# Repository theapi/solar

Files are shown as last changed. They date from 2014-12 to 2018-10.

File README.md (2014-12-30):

Solar
=====

Experiments with solar panels

To set up usb serial communication between the Pi and the Arduino:

Install arduino:
```sudo apt-get install arduino```

Give the pi user permission to use the serial connection:
```sudo usermod -a -G dialout pi```

Optionally install nfs for sharing the data log
From http://www.linuxuser.co.uk/tutorials/building-a-network-of-raspberry-pis

```sudo apt-get install nfs-kernel-server```

Make a shared directory
```sudo mkdir /srv/public```

Edit /etc/exports
```/srv/public *(rw,async,no_subtree_check)```

Ensure rpcbind starts on restart
```sudo update-rc.d rpcbind enable```

Connect to the share with
```
sudo mkdir /mnt/solar
sudo mount <SERVER_IP>:/srv/public /mnt/solar
```

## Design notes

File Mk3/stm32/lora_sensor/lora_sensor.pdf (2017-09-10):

## lora_sensor Project Configuration Report

# 1. Description

## 1.1. Project

Project Name | lora_sensor
Board Name | lora_sensor
Generated with: | STM32CubeMX 4.22.0
Date | 09/10/2017

## 1.2. MCU

MCU Series | STM32L0
MCU Line | STM32L0x3
MCU name | STM32L053C8Tx
MCU Package | LQFP48
MCU Pin number | 48

# 2. Pinout Configuration

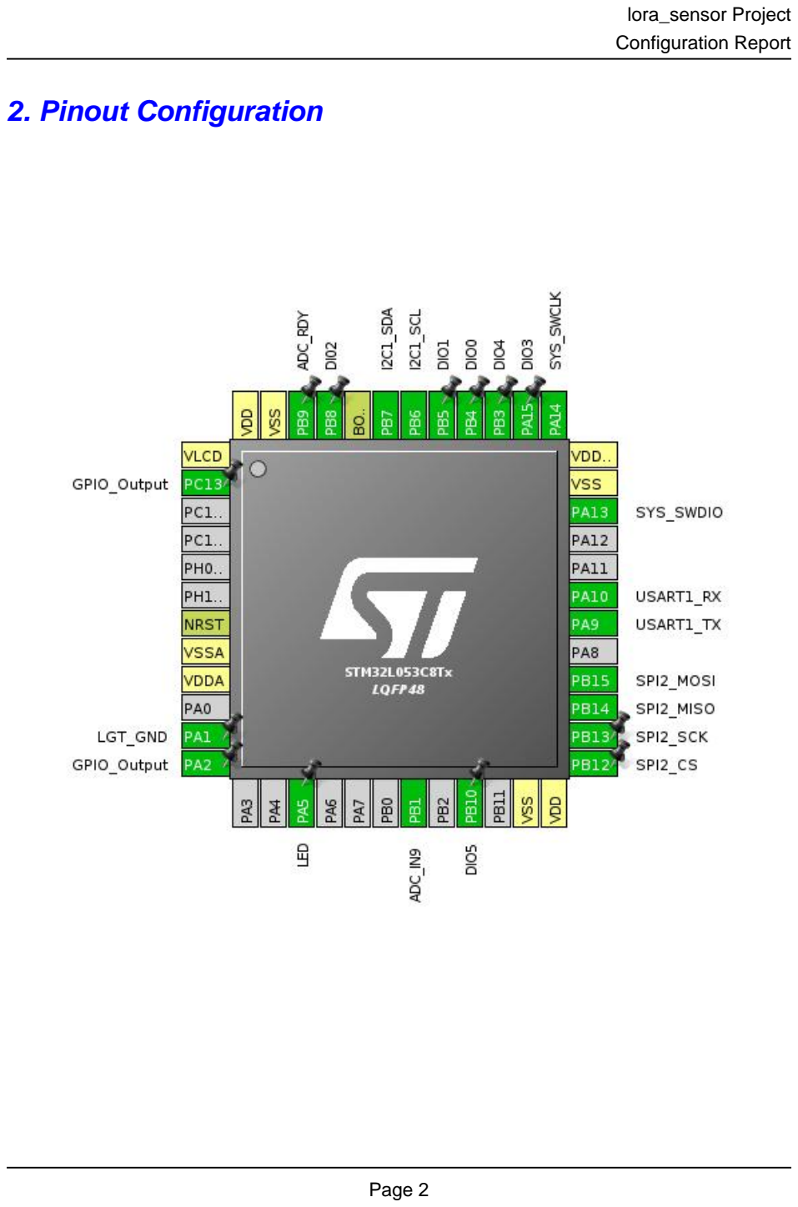
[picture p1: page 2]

# 3. Pins Configuration

Pin Number LQFP48 | Pin Name (function after reset) | Pin Type | Alternate Function(s) | Label
1 | VLCD | Power
2 | PC13 * | I/O | GPIO_Output
7 | NRST | Reset
8 | VSSA | Power
9 | VDDA | Power
11 | PA1 * | I/O | GPIO_Output | LGT_GND
12 | PA2 * | I/O | GPIO_Output
15 | PA5 * | I/O | GPIO_Output | LED
19 | PB1 | I/O | ADC_IN9
21 | PB10 * | I/O | GPIO_Analog | DIO5
23 | VSS | Power
24 | VDD | Power
25 | PB12 * | I/O | GPIO_Output | SPI2_CS
26 | PB13 | I/O | SPI2_SCK
27 | PB14 | I/O | SPI2_MISO
28 | PB15 | I/O | SPI2_MOSI
30 | PA9 | I/O | USART1_TX
31 | PA10 | I/O | USART1_RX
34 | PA13 | I/O | SYS_SWDIO
35 | VSS | Power
36 | VDD_USB | Power
37 | PA14 | I/O | SYS_SWCLK
38 | PA15 * | I/O | GPIO_Analog | DIO3
39 | PB3 * | I/O | GPIO_Analog | DIO4
40 | PB4 | I/O | GPIO_EXTI4 | DIO0
41 | PB5 * | I/O | GPIO_Analog | DIO1
42 | PB6 | I/O | I2C1_SCL
43 | PB7 | I/O | I2C1_SDA
44 | BOOT0 | Boot
45 | PB8 * | I/O | GPIO_Analog | DI02
46 | PB9 | I/O | GPIO_EXTI9 | ADC_RDY
47 | VSS | Power
48 | VDD | Power

## * The pin is affected with an I/O function

# 4. Clock Tree Configuration

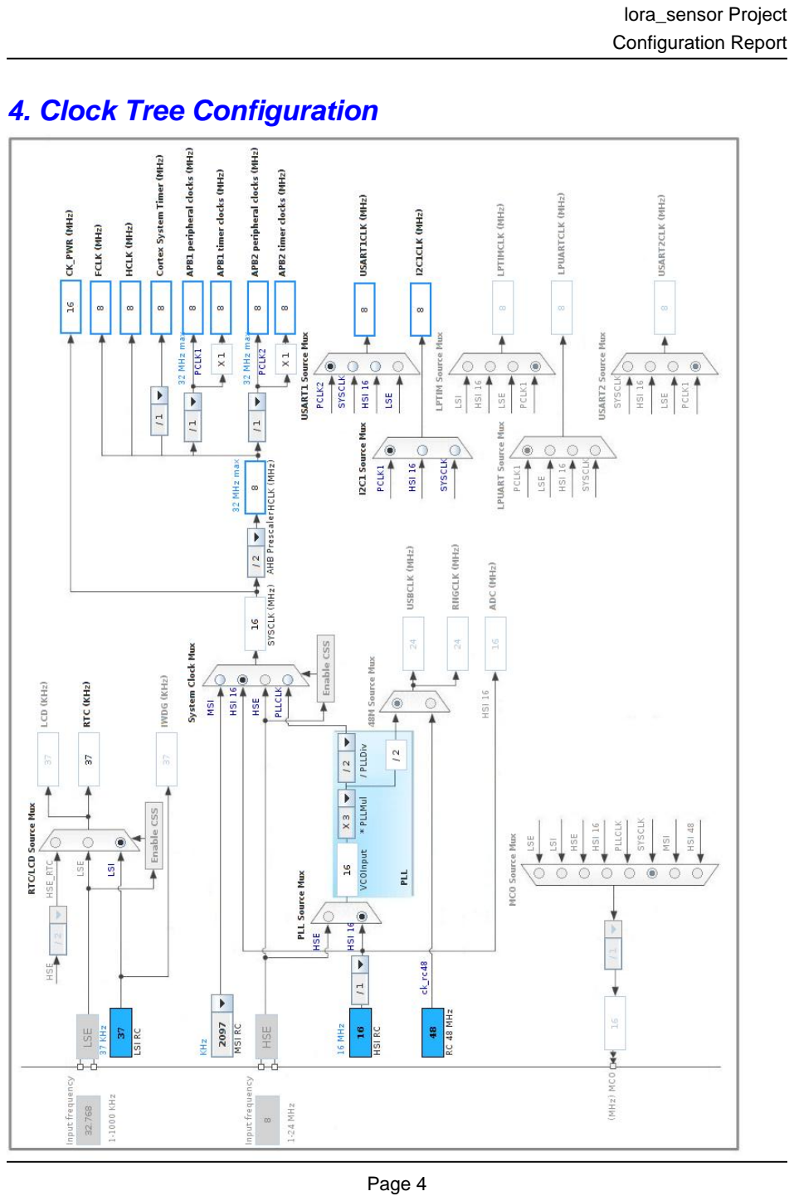
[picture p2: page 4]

# 5. IPs and Middleware Configuration

# 5.1. ADC

## mode: IN9 mode: Temperature Sensor Channel

## 5.1.1. Parameter Settings:

### ADC_Settings:

Clock Prescaler | Synchronous clock mode divided by 2
Resolution | ADC 12-bit resolution
Data Alignment | Right alignment
Scan Direction | Forward
Continuous Conversion Mode | Enabled *
Discontinuous Conversion Mode | Disabled
DMA Continuous Requests | Disabled
End Of Conversion Selection | End of single conversion
Overrun behaviour | Overrun data preserved
Low Power Auto Wait | Enabled *
Low Frequency Mode | Disabled
Auto Off | Disabled
Oversampling Mode | Disabled

### ADC_Regular_ConversionMode:

Sampling Time | 160.5 Cycles *
External Trigger Conversion Source | Regular Conversion launched by software
External Trigger Conversion Edge | None

### WatchDog:

Enable Analog WatchDog Mode | false

# 5.2. I2C1

## I2C: I2C

## 5.2.1. Parameter Settings:

### Timing configuration:

I2C Speed Mode | Standard Mode

I2C Speed Frequency (KHz) | 100
Rise Time (ns) | 0
Fall Time (ns) | 0
Coefficient of Digital Filter | 0
Analog Filter | Enabled
Timing | 0x2000090E *

### Slave Features:

Clock No Stretch Mode | Disabled
General Call Address Detection | Disabled
Primary Address Length selection | 7-bit
Dual Address Acknowledged | Disabled
Primary slave address | 0

# 5.3. RTC

## mode: Activate Clock Source mode: Activate Calendar WakeUp: Internal WakeUp

## 5.3.1. Parameter Settings:

### General:

Hour Format | Hourformat 24
Asynchronous Predivider value | 127
Synchronous Predivider value | 255

### Calendar Time:

Data Format | BCD data format
Hours | 0
Minutes | 0
Seconds | 0
Day Light Saving: value of hour adjustment | Daylightsaving None
Store Operation | Storeoperation Reset

### Calendar Date:

Week Day | Monday
Month | January
Date | 1
Year | 0

### Wake UP:

Wake Up Clock | 1 Hz *
Wake Up Counter | 0

# 5.4. SPI2

## Mode: Full-Duplex Master

## 5.4.1. Parameter Settings:

### Basic Parameters:

Frame Format | Motorola
Data Size | 8 Bits
First Bit | MSB First

### Clock Parameters:

Prescaler (for Baud Rate) | 8 *
Baud Rate | 1000.0 KBits/s *
Clock Polarity (CPOL) | Low
Clock Phase (CPHA) | 1 Edge

### Advanced Parameters:

CRC Calculation | Disabled
NSS Signal Type | Software

# 5.5. SYS

## mode: Debug Serial Wire Timebase Source: SysTick

# 5.6. USART1

## Mode: Asynchronous

## 5.6.1. Parameter Settings:

### Basic Parameters:

Baud Rate | 115200
Word Length | 8 Bits (including Parity) *
Parity | None
Stop Bits | 1

### Advanced Parameters:

Data Direction | Receive and Transmit

Over Sampling | 16 Samples
Single Sample | Disable

### Advanced Features:

Auto Baudrate | Disable
TX Pin Active Level Inversion | Disable
RX Pin Active Level Inversion | Disable
Data Inversion | Disable
TX and RX Pins Swapping | Disable
Overrun | Enable
DMA on RX Error | Enable
MSB First | Disable

### * User modified value

# 6. System Configuration

# 6.1. GPIO configuration

IP | Pin | Signal | GPIO mode | GPIO pull/up pull down | Max Speed | User Label
ADC | PB1 | ADC_IN9 | Analog mode | No pull-up and no pull-down | n/a
I2C1 | PB6 | I2C1_SCL | Alternate Function Open Drain | Pull-up | Very High *
| PB7 | I2C1_SDA | Alternate Function Open Drain | Pull-up | Very High *
SPI2 | PB13 | SPI2_SCK | Alternate Function Push Pull | No pull-up and no pull-down | Very High *
| PB14 | SPI2_MISO | Alternate Function Push Pull | No pull-up and no pull-down | Very High *
| PB15 | SPI2_MOSI | Alternate Function Push Pull | No pull-up and no pull-down | Very High *
SYS | PA13 | SYS_SWDIO | n/a | n/a | n/a
| PA14 | SYS_SWCLK | n/a | n/a | n/a
USART1 | PA9 | USART1_TX | Alternate Function Push Pull | Pull-up | Very High *
| PA10 | USART1_RX | Alternate Function Push Pull | Pull-up | Very High *
GPIO | PC13 | GPIO_Output | Output Push Pull | No pull-up and no pull-down | Low
| PA1 | GPIO_Output | Output Push Pull | No pull-up and no pull-down | Low | LGT_GND
| PA2 | GPIO_Output | Output Push Pull | No pull-up and no pull-down | Low
| PA5 | GPIO_Output | Output Push Pull | No pull-up and no pull-down | Low | LED
| PB10 | GPIO_Analog | Analog mode | No pull-up and no pull-down | n/a | DIO5
| PB12 | GPIO_Output | Output Push Pull | No pull-up and no pull-down | Low | SPI2_CS
| PA15 | GPIO_Analog | Analog mode | No pull-up and no pull-down | n/a | DIO3
| PB3 | GPIO_Analog | Analog mode | No pull-up and no pull-down | n/a | DIO4
| PB4 | GPIO_EXTI4 | External Interrupt Mode with Rising edge trigger detection | No pull-up and no pull-down | n/a | DIO0
| PB5 | GPIO_Analog | Analog mode | No pull-up and no pull-down | n/a | DIO1
| PB8 | GPIO_Analog | Analog mode | No pull-up and no pull-down | n/a | DI02
| PB9 | GPIO_EXTI9 | External Interrupt Mode with Rising edge trigger detection | No pull-up and no pull-down | n/a | ADC_RDY

# 6.2. DMA configuration

## nothing configured in DMA service

# 6.3. NVIC configuration

Interrupt Table | Enable | Preenmption Priority | SubPriority
Non maskable interrupt | true | 0 | 0
Hard fault interrupt | true | 0 | 0
System service call via SWI instruction | true | 0 | 0
Pendable request for system service | true | 0 | 0
System tick timer | true | 0 | 0
RTC global interrupt through EXTI lines 17, 19 and 20 and LSE CSS interrupt through EXTI line 19 | true | 0 | 0
EXTI line 4 to 15 interrupts | true | 0 | 0
PVD interrupt through EXTI line 16 | unused
Flash and EEPROM global interrupt | unused
RCC and CRS global interrupt | unused
ADC1, COMP1 and COMP2 interrupts (COMP interrupts through EXTI lines 21 and 22) | unused
I2C1 event global interrupt / I2C1 wake-up interrupt through EXTI line 23 | unused
SPI2 global interrupt | unused
USART1 global interrupt / USART1 wake-up interrupt through EXTI line 25 | unused

### * User modified value

# 7. Power Consumption Calculator report

### 7.1. Microcontroller Selection

Series | STM32L0
Line | STM32L0x3
MCU | STM32L053C8Tx
Datasheet | 025844_Rev6

### 7.2. Parameter Selection

Temperature | 25
Vdd | null

# 8. Software Project

## 8.1. Project Settings

Name | Value
Project Name | lora_sensor
Project Folder | /home/peter/repos/solar/Mk3/stm32/lora_sensor
Toolchain / IDE | SW4STM32
Firmware Package Name and Version | STM32Cube FW_L0 V1.9.0

## 8.2. Code Generation Settings

Name | Value
STM32Cube Firmware Library Package | Copy only the necessary library files
Generate peripheral initialization as a pair of '.c/.h' files | Yes
Backup previously generated files when re-generating | No
Delete previously generated files when not re-generated | Yes
Set all free pins as analog (to optimize the power consumption) | Yes

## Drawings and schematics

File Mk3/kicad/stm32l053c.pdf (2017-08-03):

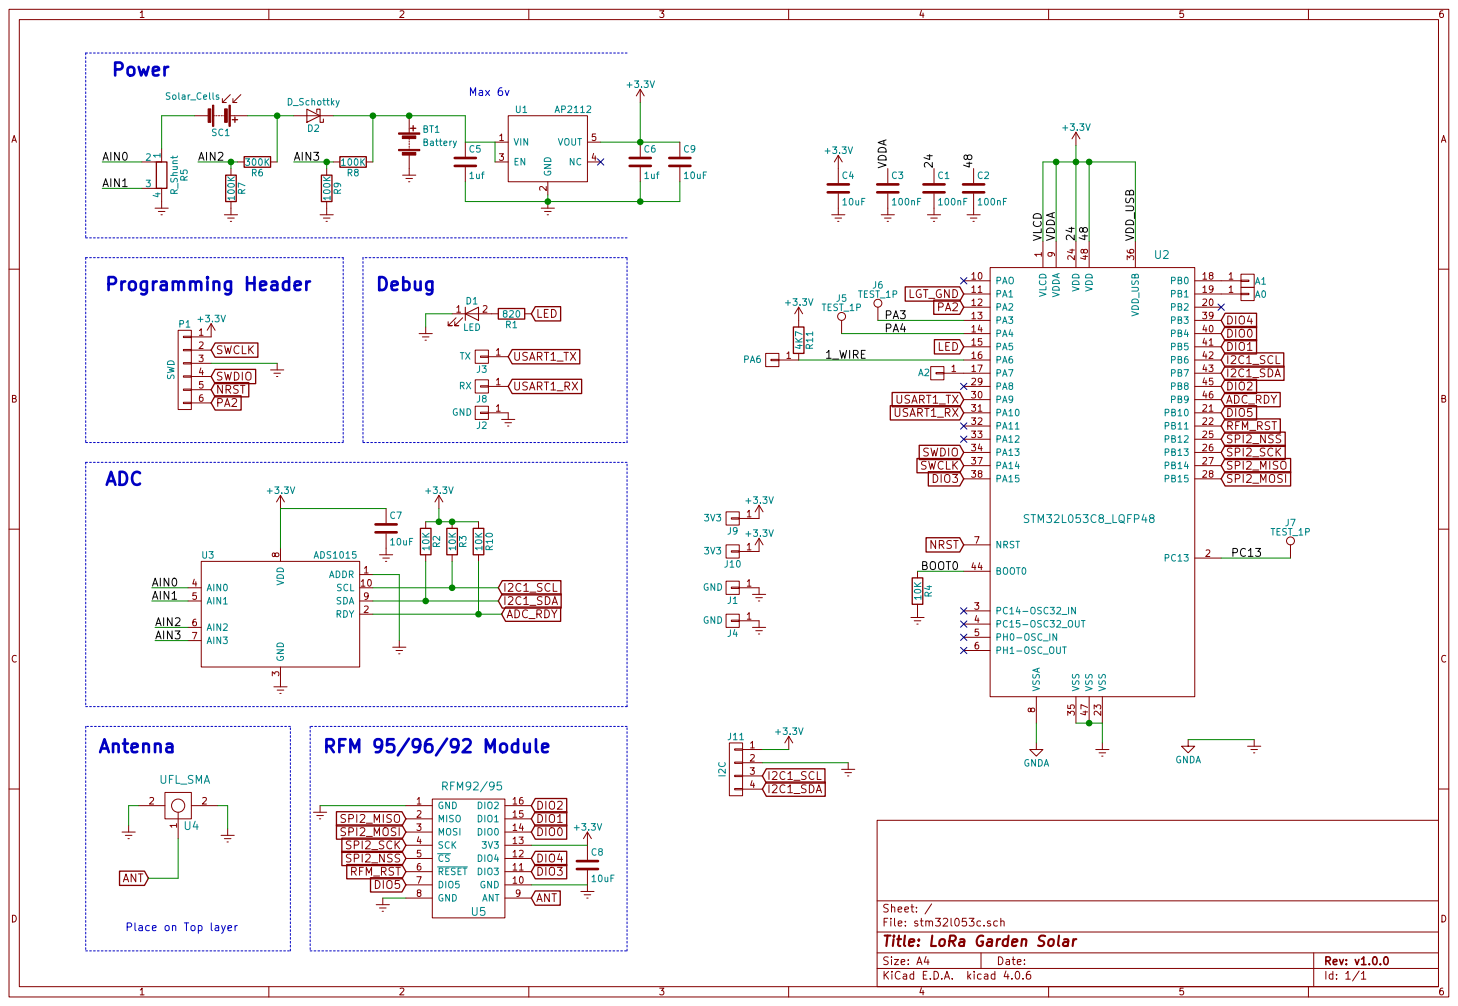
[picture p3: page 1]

2 EN 3 NC 4 VOUT 5 U1 AP2112 Power

9 PAO 10 PB2 20 PA9 30 PB4 40 PA1 11 PB10 21 PA10 31 PB5 41 PA2 12 PB11 22 PA11 32 PB6 42 PA3 13 VSS 23 PA12 33 PB7 43 PA4 14 VDD 24 PA13 34 BOOT0 44 PA5 15 PB12 25 VSS 35 PB8 45 PA6 16 PB13 26 VDD_USB 36 PB9 46 PA7 17 PB14 27 PA14 37 VSS 47 PB0 18 PB15 28 PA15 38 VDD 48 PB1 19 PA8 29 PB3 39 U2 STM32L053C8_LQFP48 R4 10K R1

8 SDA 9 SCL 10 U3 ADS1015 ANT Antenna RFM 95/96/92 Module

Id: 1/1 Title: LoRa Garden Solar File: stm32l053c.sch Sheet: /

Place on Top layer

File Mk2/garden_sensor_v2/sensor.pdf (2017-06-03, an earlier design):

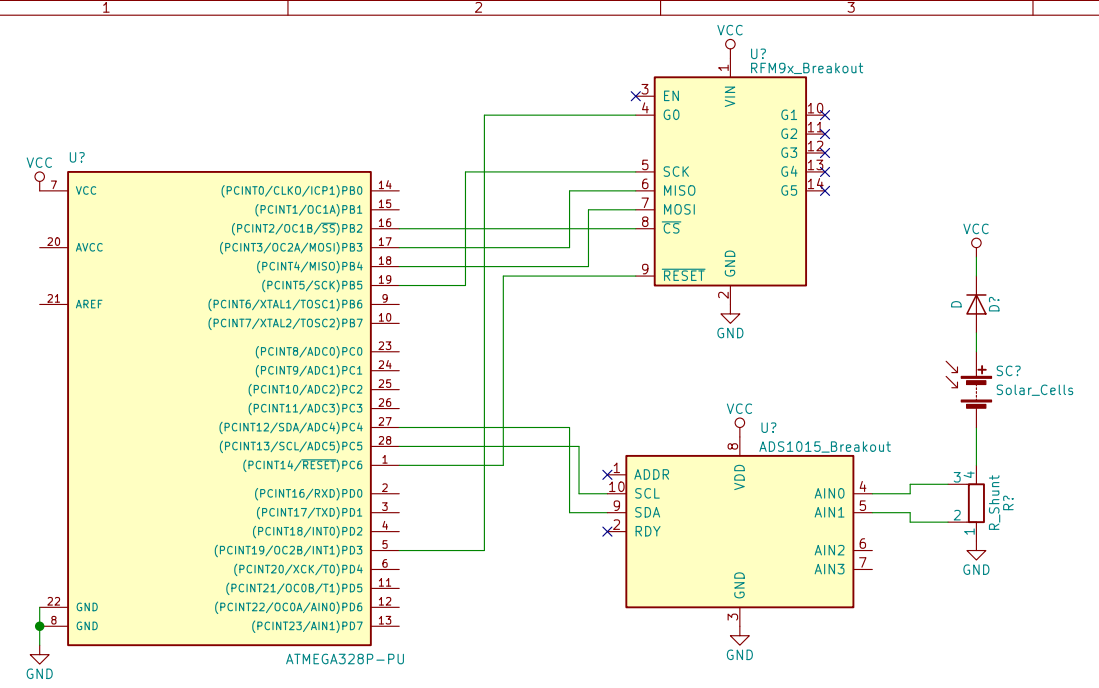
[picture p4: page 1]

2 EN 3 G0 4 SCK 5 MISO 6 MOSI 7 CS 8 RESET 9 G1 10 G2 11 G3 12 G4 13 G5 14 U?RFM9x_Breakout 1

8 SDA 9 SCL 10 U?ADS1015_Breakout VCC GND GND

Id: 1/1 Title: File: sensor.sch Sheet: /

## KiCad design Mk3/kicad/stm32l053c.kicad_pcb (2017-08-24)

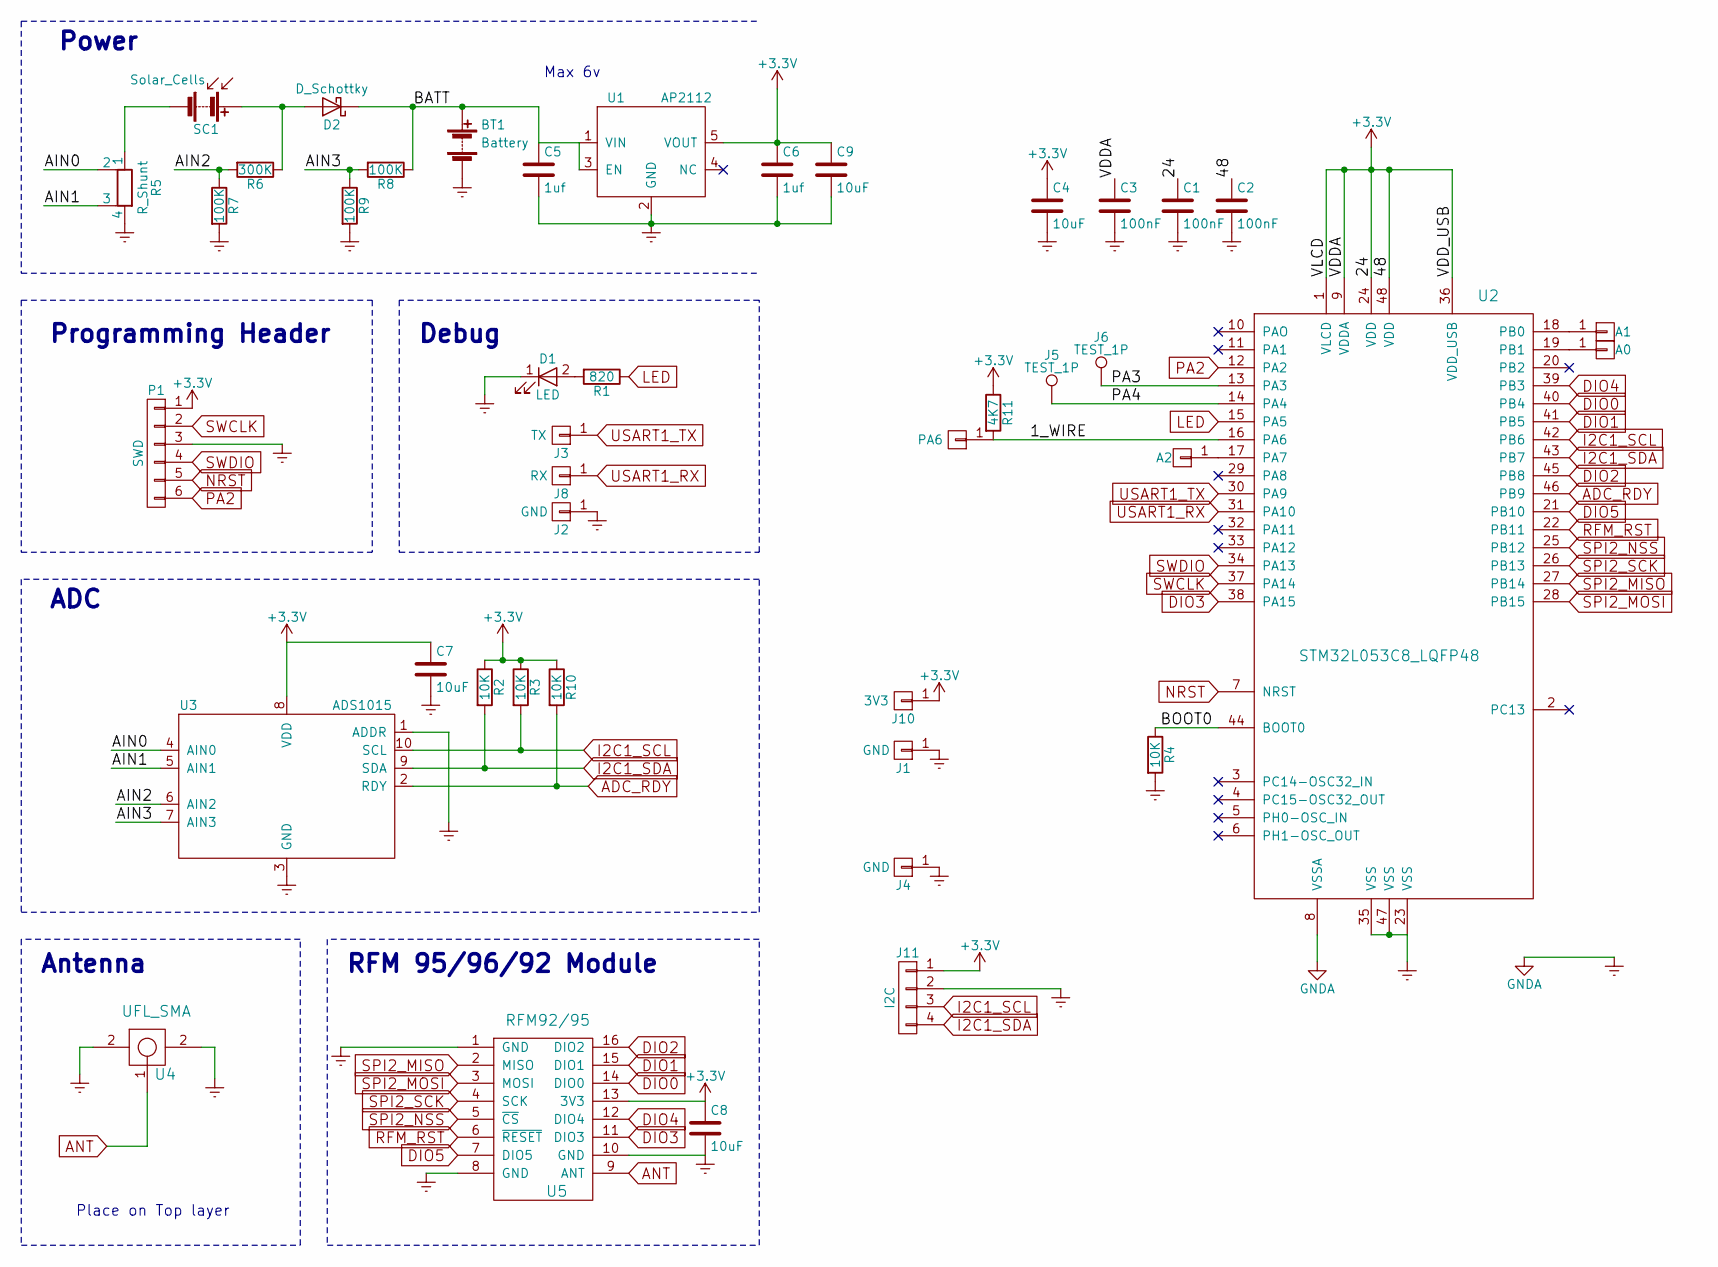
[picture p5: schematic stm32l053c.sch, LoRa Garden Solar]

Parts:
A0: A0; Pin_Header_Straight_1x01_Pitch2.54mm
A1: A1; Pin_Header_Straight_1x01_Pitch2.54mm
A2: A2; Pin_Header_Straight_1x01_Pitch2.54mm
BT1: Battery; BatteryBoxAndPins
C1, C2, C3: 100nF; C_0805_HandSoldering
C4, C7, C8, C9: 10uF; C_0805_HandSoldering
C5, C6: 1uf; C_0805_HandSoldering
D1: LED; LED_0805
D2: D_Schottky; D_SOD-323_HandSoldering
J1, J2, J4: GND; Pin_Header_Straight_1x01_Pitch2.54mm
J3: TX; Pin_Header_Straight_1x01_Pitch2.54mm
J5, J6: TEST_1P; TestPoint
J8: RX; Pin_Header_Straight_1x01_Pitch2.54mm
J10: 3V3; Pin_Header_Straight_1x01_Pitch2.54mm
J11: I2C; Pin_Header_Straight_1x04_Pitch2.54mm
P1: SWD; Pin_Header_Straight_1x06_Pitch2.54mm
PA6: A3; Pin_Header_Straight_1x01_Pitch2.54mm
R1: 820; R_0805_HandSoldering
R2, R3, R4, R10: 10K; R_0805_HandSoldering
R5: R_Shunt; SHUNT_1210_HandSoldering
R6: 300K; R_0805_HandSoldering
R7, R8, R9: 100K; R_0805_HandSoldering
R11: 4K7; R_0805_HandSoldering
SC1: Solar_Cells; Pin_Header_Straight_1x02_Pitch2.54mm
U1: AP2112; SOT-23-5_HandSoldering
U2: STM32L053C8_LQFP48; LQFP-48_7x7mm_Pitch0.5mm
U3: ADS1015; TSSOP-10_3x3mm_Pitch0.5mm
U4: UFL_SMA; coaxial_u.fl-r-smt-1
U5: RFM92/95; RFM92_95_96_98; MPN ...

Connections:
+3V3: C1.1, C2.1, C3.1, C4.1, C6.1, C7.1, C8.1, C9.1, J10.1, J11.1, P1.1, R2.1, R3.1, R10.1, R11.1, U1.5 (VOUT), U2.1 (VLCD), U2.9 (VDDA), U2.24 (VDD), U2.36 (VDD_USB), U2.48 (VDD), U3.8 (VDD), U5.13 (3V3)
/1_WIRE: PA6.1, R11.2, U2.16 (PA6)
/AIN0: R5.2, U3.4 (AIN0)
/AIN1: R5.3, U3.5 (AIN1)
/AIN2: R6.2, R7.1, U3.6 (AIN2)
/AIN3: R8.2, R9.1, U3.7 (AIN3)
/BATT: BT1.1 (+), C5.1, D2.1 (K), R8.1, U1.1 (VIN), U1.3 (EN)
/BOOT0: R4.1, U2.44 (BOOT0)
/PA3: J6.1, U2.13 (PA3)
/PA4: J5.1, U2.14 (PA4)
ADC_RDY: R10.2, U2.46 (PB9), U3.2 (RDY)
ANT: U4.1, U5.9 (ANT)
DIO0: U2.40 (PB4), U5.14 (DIO0)
DIO1: U2.41 (PB5), U5.15 (DIO1)
DIO2: U2.45 (PB8), U5.16 (DIO2)
DIO3: U2.38 (PA15), U5.11 (DIO3)
DIO4: U2.39 (PB3), U5.12 (DIO4)
DIO5: U2.21 (PB10), U5.7 (DIO5)
Earth: BT1.2 (-), C1.2, C2.2, C3.2, C4.2, C5.2, C6.2, C7.2, C8.2, C9.2, D1.1 (K), J1.1, J2.1, J4.1, J11.2, P1.3, R4.2, R5.4, R7.2, R9.2, U1.2 (GND), U2.8 (VSSA), U2.23 (VSS), U2.35 (VSS), U2.47 (VSS), U3.1 (ADDR), U3.3 (GND), U4.2, U5.1 (GND), U5.8 (GND), U5.10 (GND)
I2C1_SCL: J11.3, R3.2, U2.42 (PB6), U3.10 (SCL)
I2C1_SDA: J11.4, R2.2, U2.43 (PB7), U3.9 (SDA)
LED: R1.1, U2.15 (PA5)
NRST: P1.5, U2.7 (NRST)
unnamed: A0.1, U2.19 (PB1)
unnamed: A1.1, U2.18 (PB0)
unnamed: A2.1, U2.17 (PA7)
unnamed: D1.2 (A), R1.2
unnamed: D2.2 (A), R6.1, SC1.1 (+)
unnamed: R5.1, SC1.2 (-)
PA2: P1.6, U2.12 (PA2)
RFM_RST: U2.22 (PB11), U5.6 (~RESET)
SPI2_MISO: U2.27 (PB14), U5.2 (MISO)
SPI2_MOSI: U2.28 (PB15), U5.3 (MOSI)
SPI2_NSS: U2.25 (PB12), U5.5 (~CS)
SPI2_SCK: U2.26 (PB13), U5.4 (SCK)
SWCLK: P1.2, U2.37 (PA14)
SWDIO: P1.4, U2.34 (PA13)
USART1_RX: J8.1, U2.31 (PA10)
USART1_TX: J3.1, U2.30 (PA9)

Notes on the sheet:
Antenna
RFM 95/96/92 Module
Place on Top layer
ADC
Programming Header
Power
Max 6v
Debug

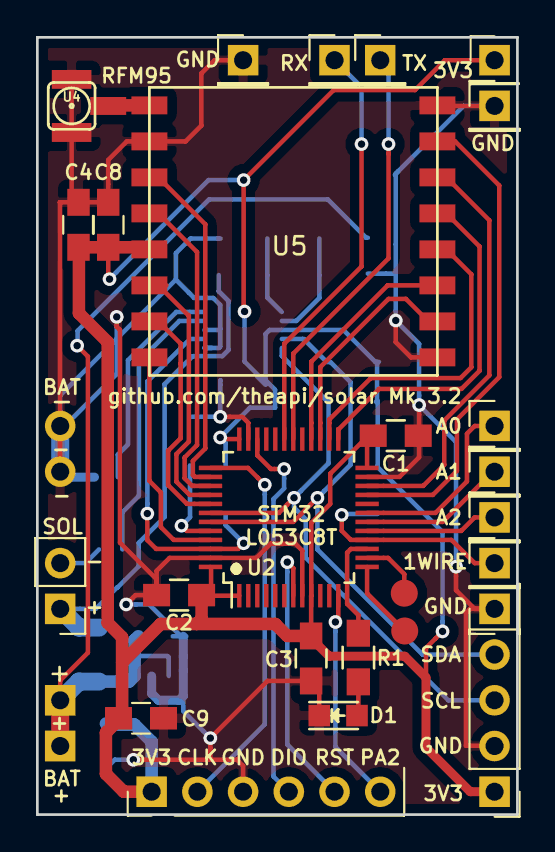
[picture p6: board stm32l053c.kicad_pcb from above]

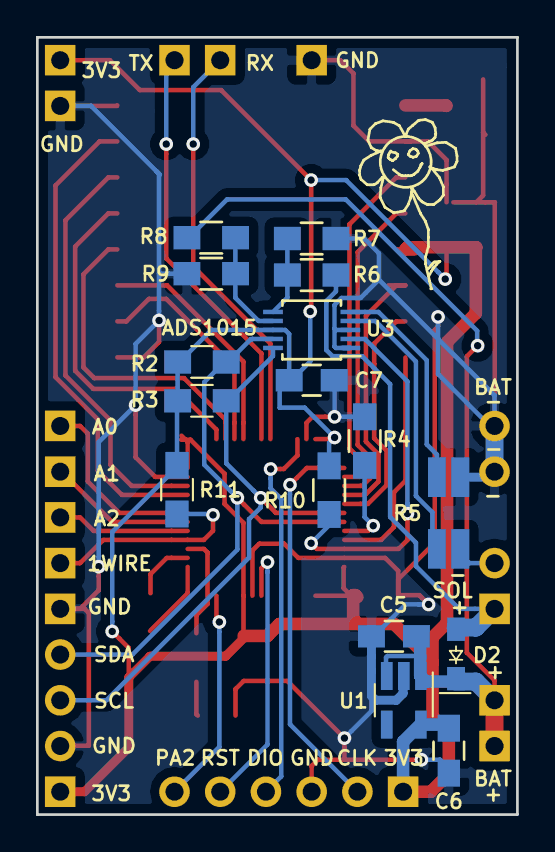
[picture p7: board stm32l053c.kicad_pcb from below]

Board: 2 copper layers, 26.7 x 43.2 mm, 43 parts (16 on the bottom side), 39 nets.

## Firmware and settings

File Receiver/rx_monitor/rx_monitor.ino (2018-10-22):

/**
 * Takes a serial payload from the LoRa client (LoRa_Radiohead_RX.ino)
 * and publishes it on various protocols.
 *
 * To subscribe to the UDP data: listen for broadcasts on 239.0.0.57 port 12345
 * To subscribe to the MQTT data: mosquitto_sub -t solar
 * To subscribe to the websocket go to WiFi.localIP() port 80
 */

#include <ESP8266WiFi.h>
#include <WiFiUdp.h>
#include <WebSocketsServer.h>
#include <ESP8266WebServer.h>
#include <PubSubClient.h>
#include "config.h"
#include "SSD1306.h"
#include "Payload.h"
#include "GardenPayload.h"
#include "SolarPayload.h"
#include "html.h"

// A UDP instance to let us send and receive packets over UDP
WiFiUDP Udp;

// Multicast declarations
IPAddress ipMulti(239, 0, 0, 57);
unsigned int portMulti = 12345;      // local port to listen on

ESP8266WebServer server(80);
WebSocketsServer webSocket = WebSocketsServer(81);

WiFiClient espClient;
PubSubClient mqtt_client(espClient);

// Initialize the OLED display using Wire library
SSD1306  display(0x3c, 4, 5);

theapi::SolarPayload solar_payload = theapi::SolarPayload();
theapi::GardenPayload rx_payload = theapi::GardenPayload();
uint8_t input_string[32];
uint8_t payload_state = 0;
uint8_t current_payload;
uint8_t serial_byte_count = 0;

// The degrees are sent as an int that needs to be divided by 100.
// floats a twice as large as we need for transmission.
float deg = -42.0;

unsigned long message_last = 0;
uint8_t last_msg_id = 0;

unsigned long display_last = 0;
const long display_interval = 1000;

const long ping_interval = 3000;
unsigned long ping_last = 0;

const char* mqtt_server = MQTT_SERVER;
uint16_t mqtt_port = MQTT_PORT;

int display_status = 0;

String ip_end;

void webSocketEvent(uint8_t num, WStype_t type, uint8_t * payload, size_t length) {

  switch (type) {
    case WStype_DISCONNECTED:
      Serial.printf("[%u] Disconnected!\n", num);
      break;
    case WStype_CONNECTED: {
        IPAddress ip = webSocket.remoteIP(num);
        Serial.printf("[%u] Connected from %d.%d.%d.%d url: %s\n", num, ip[0], ip[1], ip[2], ip[3], payload);

        // send message to client
        //webSocket.sendTXT(num, "{\"status\": \"Connected\"}");
        websocketBroadcastGarden();
      }
      break;
  }

}

void setup() {
  Serial.begin(115200);
  Serial.println();

  // Initialise the display.
  display.init();
  //display.flipScreenVertically();
  display.setFont(ArialMT_Plain_16);

  display.clear();
  display.drawString(10, 20, "Hello :)");
  display.display();


  WiFi.begin(ssid, password);
  Serial.print("\nConnecting to "); Serial.println(ssid);
  uint8_t i = 0;
  while (WiFi.status() != WL_CONNECTED && i++ < 20) delay(500);
  if(i == 21){
    Serial.print("Could not connect to"); Serial.println(ssid);
    while(1) delay(500);
  }

    // start webSocket server
  webSocket.begin();
  webSocket.onEvent(webSocketEvent);

  // handle index
  server.on("/", []() {
    // send PROGMEM index html.
    server.send_P(200, "text/html", index_html);
  });

  server.begin();

  mqtt_client.setServer(mqtt_server, mqtt_port);

  Serial.print("Web server on: ");
  Serial.println(WiFi.localIP());
  Serial.println("Ready! Listen for UDP broadcasts on 239.0.0.57 port 12345");

  String ip = WiFi.localIP().toString();
  ip_end = ip.substring(ip.lastIndexOf('.'));

}

void loop() {
  webSocket.loop();
  server.handleClient();

  // Read the data from the LoRa receiver.
  while (Serial.available()) {
    // get the new byte:
    uint8_t in = (uint8_t) Serial.read();
    //Serial.println(in, HEX);

    if (payload_state == 0) {
      // Check for the start of the payload
      if (in == '\t') {
        payload_state = 1;
      }
    } else if (payload_state == 1) {

      // Check the first byte for the payload type.
      if (serial_byte_count == 0) {
        current_payload = in;
      }

      //Serial.print(in, HEX);
      // add it to the inputString:
      input_string[serial_byte_count] = in;
      ++serial_byte_count;

      // if the the last byte is received, set a flag
      // so the main loop can do something about it:
      switch (current_payload) {
        case theapi::Payload::GARDEN:
          // Use GardenPayload
          if (serial_byte_count == rx_payload.size()) {
            serial_byte_count = 0;
            payload_state = 2;
            rx_payload.unserialize(input_string);

            // Convert the temperature to a float.
            deg = (float) rx_payload.getTemperature() / 10.0;
          }
          break;

        case theapi::Payload::SOLAR:
          // Use SolarPayload
          if (serial_byte_count == solar_payload.size()) {
            serial_byte_count = 0;
            payload_state = 2;
            solar_payload.unserialize(input_string);
          }
          break;
      }
    } else {
      // Passthru other serial messages.
      Serial.print(char(in));

    }
  }

  unsigned long currentMillis = millis();

  // Send payload to listeners when ready.
  if (payload_state == 2) {
    payload_state = 0;

    // No need to ping if we're sending real data.
    ping_last = currentMillis;
    udpBroadcast();
    websocketBroadcast();
    //mqttBroadcast();
    serialPrintPayload();

    current_payload = 0;
  }
  // Send the data continually, as its UDP some may get missed.
  else if (currentMillis - ping_last >= ping_interval) {
    ping_last = currentMillis;
    udpBroadcast();
  }

  // Update the display
  if (currentMillis - display_last >= display_interval) {
    display_last = currentMillis;

    uint8_t msg_id = rx_payload.getMsgId();
    if (msg_id != last_msg_id) {
      last_msg_id = msg_id;
      message_last = currentMillis;
    }

    display.clear();

    // How long since last message.
    display.drawString(0, 0, String((currentMillis - message_last )/ 1000));


    display.drawString(60, 0, String(msg_id));

    // Show the end of the ip address.
    display.drawString(100, 0, ip_end);

    // Second row
    display.drawString(0, 20, String(rx_payload.getChargeMa()));
    display.drawString(35, 20, String(rx_payload.getChargeMv()));
    display.drawString(80, 20, String(rx_payload.getVcc()));

    // Third row
    display.drawString(0, 45, String(deg));
    display.drawString(45, 45, String(rx_payload.getCpuTemperature()));
    display.drawString(80, 45, String(rx_payload.getLight()));

    // No display when dark.
    int ldr = analogRead(A0);
    //Serial.print("LDR: "); Serial.println(ldr);
    if (display_status == 1 && ldr < 10) {
      display_status = 0;
    } else if (display_status == 0 && ldr > 20) {
      display_status = 1;
    }

    if (display_status == 0) {
      display.clear();
    }
    display.display();
  }


}

void serialPrintPayload() {
  switch (current_payload) {
    case theapi::Payload::GARDEN:
      {
      Serial.print("GARDEN: ");
      Serial.print(rx_payload.getMsgType()); Serial.print(", ");
      Serial.print(rx_payload.getMsgId()); Serial.print(", ");
      Serial.print(rx_payload.getVcc()); Serial.print(", ");
      Serial.print(rx_payload.getChargeMv()); Serial.print(", ");
      Serial.print(rx_payload.getChargeMa()); Serial.print(", ");
      Serial.print(rx_payload.getLight()); Serial.print(", ");
      Serial.print(rx_payload.getCpuTemperature()); Serial.print(", ");
      Serial.println(deg);
      int16_t rssi = rx_payload.getRssi();
      Serial.print(rssi); Serial.print(", ");
      int16_t snr = rx_payload.getSnr();
      Serial.print(snr); Serial.print(", ");
      int16_t freq = rx_payload.getFreqError();
      Serial.print(freq); Serial.print(", ");
      Serial.println();
      }
    break;

    case theapi::Payload::SOLAR:
      {
      Serial.print("SOLAR: ");
      Serial.print(solar_payload.getMsgType()); Serial.print(", ");
      Serial.print(solar_payload.getDeviceId()); Serial.print(", ");
      Serial.print(solar_payload.getMsgId()); Serial.print(", ");
      Serial.print(solar_payload.getVcc()); Serial.print(", ");
      Serial.print(solar_payload.getChargeMv()); Serial.print(", ");
      Serial.print(solar_payload.getChargeMa()); Serial.print(", ");
      Serial.print(solar_payload.getLight()); Serial.print(", ");
      Serial.print(solar_payload.getTemperature()); Serial.print(", ");
      Serial.print(solar_payload.getCpuTemperature()); Serial.print(", ");
      int16_t rssi = solar_payload.getRssi();
      Serial.print(rssi); Serial.print(", ");
      int16_t snr = solar_payload.getSnr();
      Serial.print(snr); Serial.print(", ");
      int16_t freq = solar_payload.getFreqError();
      Serial.print(freq); Serial.print(", ");
      Serial.println();
     }
  }
}

void udpBroadcast() {
  udpBroadcastGarden();
  udpBroadcastSolar();
}

void udpBroadcastGarden() {
  Udp.beginPacketMulticast(ipMulti, portMulti, WiFi.localIP());
  Udp.write('\t'); // Payload start byte

  // Send the contents of the buffer.
  size_t len = rx_payload.size();
  uint8_t sbuf[len];
  rx_payload.serialize(sbuf);
  Udp.write(sbuf, len);

  Udp.write('\n');
  Udp.endPacket();
  Udp.stop();
}

void udpBroadcastSolar() {
  Udp.beginPacketMulticast(ipMulti, portMulti, WiFi.localIP());
  Udp.write('\t'); // Payload start byte

  // Send the contents of the buffer.
  size_t len = solar_payload.size();
  uint8_t sbuf[len];
  solar_payload.serialize(sbuf);
  Udp.write(sbuf, len);

  Udp.write('\n');
  Udp.endPacket();
  Udp.stop();
}


/**
 * Send the garden data as json
 */
void websocketBroadcastGarden() {
  String str;
  str = "{\"garden\":{";
  str += "\"msg_type\":" + String(rx_payload.getMsgType()) + ", ";
  str += "\"msg_id\":" + String(rx_payload.getMsgId()) + ",";
  str += "\"vcc\":" + String(rx_payload.getVcc()) + ",";
  str += "\"solar_mv\":" + String(rx_payload.getChargeMv()) + ",";
  str += "\"charge_ma\":" + String(rx_payload.getChargeMa()) + ",";
  str += "\"light\":" + String(rx_payload.getLight()) + ",";
  str += "\"cpu\":" + String(rx_payload.getCpuTemperature()) + ",";
  str += "\"temperature\":" + String(deg) + ",";
  str += "\"rssi\":" + String(rx_payload.getRssi()) + ",";
  str += "\"snr\":" + String(rx_payload.getSnr()) + ",";
  str += "\"freq_error\":" + String(rx_payload.getFreqError());
  str += "}}";
  webSocket.broadcastTXT(str);
}

void websocketBroadcast() {
  websocketBroadcastGarden();
}

bool mqttConnect() {
  // Connect if needed.
  if (!mqtt_client.connected()) {
    Serial.print("Attempting MQTT connection...");
    // Attempt to connect
    if (mqtt_client.connect("SolarClient")) {
      Serial.println("connected");
      return true;
    } else {
      Serial.print("failed, rc=");
      Serial.print(mqtt_client.state());
      return true;
    }
  }
  return true;
}

void mqttBroadcast() {

  String str;
  char msg[50];

  switch (current_payload) {
    default:
    {
      str = String(rx_payload.getMsgType()) + ",";
      str += String(rx_payload.getMsgId()) + ",";
      str += String(rx_payload.getVcc()) + ",";
      str += String(rx_payload.getChargeMv()) + ",";
      str += String(rx_payload.getChargeMa()) + ",";
      str += String(rx_payload.getLight()) + ",";
      str += String(rx_payload.getCpuTemperature()) + ",";
      str += String(deg) + ",";
      str += String(rx_payload.getRssi()) + ",";
      str += String(rx_payload.getSnr()) + ",";
      str += String(rx_payload.getFreqError());
      memset(msg, 0, sizeof msg);
      str.toCharArray(msg, sizeof msg);
      if (mqttConnect()) {
        mqtt_client.publish("solar/garden", msg);
      }
    }
    break;
  }

}

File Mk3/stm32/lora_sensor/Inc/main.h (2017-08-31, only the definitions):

#define LGT_GND_Pin GPIO_PIN_1
#define LGT_GND_GPIO_Port GPIOA
#define LED_Pin GPIO_PIN_5
#define LED_GPIO_Port GPIOA
#define DIO5_Pin GPIO_PIN_10
#define DIO5_GPIO_Port GPIOB
#define SPI2_CS_Pin GPIO_PIN_12
#define SPI2_CS_GPIO_Port GPIOB
#define DIO3_Pin GPIO_PIN_15
#define DIO3_GPIO_Port GPIOA
#define DIO4_Pin GPIO_PIN_3
#define DIO4_GPIO_Port GPIOB
#define DIO0_Pin GPIO_PIN_4
#define DIO0_GPIO_Port GPIOB
#define DIO0_EXTI_IRQn EXTI4_15_IRQn
#define DIO1_Pin GPIO_PIN_5
#define DIO1_GPIO_Port GPIOB
#define DI02_Pin GPIO_PIN_8
#define DI02_GPIO_Port GPIOB
#define ADC_RDY_Pin GPIO_PIN_9
#define ADC_RDY_GPIO_Port GPIOB
#define ADC_RDY_EXTI_IRQn EXTI4_15_IRQn

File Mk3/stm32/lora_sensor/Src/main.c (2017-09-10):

/**
  ******************************************************************************
  * File Name          : main.c
  * Description        : Main program body
  ******************************************************************************
  ** This notice applies to any and all portions of this file
  * that are not between comment pairs USER CODE BEGIN and
  * USER CODE END. Other portions of this file, whether 
  * inserted by the user or by software development tools
  * are owned by their respective copyright owners.
  *
  * COPYRIGHT(c) 2017 STMicroelectronics
  *
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
  ******************************************************************************
  */
/* Includes ------------------------------------------------------------------*/
#include "main.h"
#include "stm32l0xx_hal.h"
#include "adc.h"
#include "i2c.h"
#include "rtc.h"
#include "spi.h"
#include "usart.h"
#include "gpio.h"

/* USER CODE BEGIN Includes */

#include "string.h"

#include "rfm95.h"
#include "payload_garden.h"
#include "ads1015.h"
#include "battery.h"
#include "temperature.h"
#include "light.h"

/* USER CODE END Includes */


/* USER CODE BEGIN PV */

/* USER CODE END PV */

void SystemClock_Config(void);
static void MX_NVIC_Init(void);

/* USER CODE BEGIN PFP */

/* USER CODE END PFP */

/* USER CODE BEGIN 0 */

volatile uint8_t dio0_action = 0;
MAIN_StateTypeDef state;

/* USER CODE END 0 */

int main(void)
{

  /* MCU Configuration----------------------------------------------------------*/

  /* Reset of all peripherals, Initializes the Flash interface and the Systick. */
  HAL_Init();

  /* Configure the system clock */
  SystemClock_Config();

  /* Initialize all configured peripherals */
  MX_GPIO_Init();
  MX_ADC_Init();
  MX_I2C1_Init();
  MX_RTC_Init();
  MX_USART1_UART_Init();
  MX_SPI2_Init();

  /* Initialize interrupts */
  MX_NVIC_Init();

  /* USER CODE BEGIN 2 */

  HAL_ADCEx_Calibration_Start(&hadc, ADC_SINGLE_ENDED);

    /* Enable Ultra low power mode */
    HAL_PWREx_EnableUltraLowPower();
    __HAL_RCC_WAKEUPSTOP_CLK_CONFIG(RCC_STOP_WAKEUPCLOCK_HSI);

    /* Buffer used for transmission on USART1 */
    char tx1_buffer[120];


    RFM95_init(&hspi2);

    uint8_t payload_buff[14];
    PAYLOAD_Garden payload_garden;
    payload_garden.MessageType = 50;
    payload_garden.MessageId = 0;


    // Start in sensing mode.
    state = MAIN_STATE_SENSE;

  /* USER CODE END 2 */

  /* Infinite loop */
  /* USER CODE BEGIN WHILE */
    while (1) {
  /* USER CODE END WHILE */

  /* USER CODE BEGIN 3 */

        /* Do some work */
        if (state == MAIN_STATE_SENSE) {
            HAL_ADC_Start(&hadc);
            // junk readings
            payload_garden.Temperature = TEMPERATURE_external();
            payload_garden.CpuTemperature = TEMPERATURE_cpu();

            HAL_GPIO_WritePin(GPIOA, LED_Pin, GPIO_PIN_SET);

            payload_garden.MessageId++;
            payload_garden.VCC = BATTERY_vcc();
            payload_garden.ChargeMv = BATTERY_ChargeMv();
            payload_garden.ChargeMa = BATTERY_ChargeMa();



            /* Get the light reading while the adc gets ready */
            payload_garden.Light = LIGHT_lux();

            payload_garden.Temperature = TEMPERATURE_external();
            payload_garden.CpuTemperature = TEMPERATURE_cpu();
            HAL_ADC_Stop(&hadc);

            sprintf(tx1_buffer, "id:%d, vcc:%d, mv:%d, ma:%d, C:%d, cpuC:%d, lux:%d\n",
                    payload_garden.MessageId,
                    payload_garden.VCC,
                    payload_garden.ChargeMv,
                    payload_garden.ChargeMa,
                    payload_garden.Temperature,
                    payload_garden.CpuTemperature,
                    payload_garden.Light);
            HAL_UART_Transmit(&huart1, (uint8_t*) tx1_buffer, strlen(tx1_buffer), 1000);

            PAYLOAD_Garden_serialize(payload_garden, payload_buff);
            RFM95_send(&hspi2, payload_buff, 14);

            state = MAIN_STATE_TX;
        }

        /* Do nothing while the transmission is in progress */
        else if (state == MAIN_STATE_TX) {
            if (dio0_action == 1) {
                RFM95_setMode(&hspi2, RFM95_MODE_SLEEP);
                state = MAIN_STATE_SLEEP;
            }

            //TMP while interrupts are investigated
            //HAL_Delay(30);
            //state = MAIN_STATE_SLEEP;
        }

        /* Now that all the work is done, sleep until its time to do it all again */
        else if (state == MAIN_STATE_SLEEP) {
            HAL_GPIO_WritePin(GPIOA, LED_Pin, GPIO_PIN_RESET);

            //TMP while RFM is diabled
            //HAL_Delay(1000);

            /* Turn off the pin interrupts */
            HAL_NVIC_DisableIRQ(EXTI4_15_IRQn);

            HAL_SuspendTick();

            /* Enter Stop Mode */
            HAL_RTCEx_SetWakeUpTimer_IT(&hrtc, 60,
            RTC_WAKEUPCLOCK_CK_SPRE_16BITS);
            HAL_PWR_EnterSTOPMode(PWR_LOWPOWERREGULATOR_ON, PWR_STOPENTRY_WFI);
            HAL_RTCEx_DeactivateWakeUpTimer(&hrtc);
            HAL_ResumeTick();

            /* Turn on the pin interrupts */
            HAL_NVIC_EnableIRQ(EXTI4_15_IRQn);

            state = MAIN_STATE_SENSE;
        }

    }
  /* USER CODE END 3 */

}
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

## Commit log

2014-04-27 ATTiny85 with brown out detector at 2.7v with watchdog checking for cpu freeze every 4 seconds
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2014-05-07 Use ServoTimer2 so that virtualwire can also be used
2014-05-10 Disabled virtual wire as it makes the servo jump
2014-05-10 Use the servo library as it smoother
2014-05-11 Move the servo from pin 10 so it can be used later for SPI
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2014-05-13 i2c demo between Nanos/Unos
2014-05-14 Communicated with other i2c slave with I2Cserial
2014-05-14 No need to analogRead() the wakeup pin
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2014-05-21 Hacked virtualwire to use timer2
2014-05-22 Start of power management
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2014-05-28 log what is sent from the device
2014-05-28 Do not detach servo, saves power
2014-05-29 Only log data from the solar device
2014-05-29 Start of simplified solar powered sensor
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2014-06-08 Use vcc for internal temperature calculation
2014-08-06 Experimental attiny85 solar powered receiver
2014-08-06 Shorted serial print to prevent crash
2014-08-07 PWM using timer 1
2014-08-07 Set pwm value from RF message
2014-08-20 Wake up to an interrupt not a reset
2014-08-27 Mock up of the power board
    [power.fzz]
2014-08-29 PNP to switch voltage regulator
    [power.fzz]
2014-08-29 Bare bones arduino
    [arduino.fzz]
2014-09-01 Power on main board
    [arduino.fzz]
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2014-09-22 Mmm time to move away from fritzing
    [power.fzz]
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2014-09-30 Set pwm frequency to prevent buzz on the analogue voltmeter
2014-09-30 Re-enable timer2 after sleep
2014-10-02 MCP4725 12 bit DAC as pwm is still buzzing
2014-12-30 Relay the data through the nrf24 radio network
2015-01-01 Only accept data from the "E" nrf24 radio device
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2017-04-15 Basic socket server & client
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2017-04-16 Broadcast UDP socket client
2017-04-18 LEDs on the front panel
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2017-04-24 Set current_payload to the value of the first byte
2017-04-24 Serialize with the correct object
    [LoRa_RX.ino]
2017-04-27 Faster but shorter distance
    [LoRa_RX.ino]
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2017-05-03 Current on the OLED
2017-05-05 Removed OLED, and handle slow switching to Internal aref
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2017-05-08 Use the external ADC for the solar panel volts
2017-05-09 Start of Google charts
    [example.csv]
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2017-05-22 Folder restructure
    [arduino.fzz, sensor.kicad_pcb, sensor.sch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]
2017-05-22 Example watchdog reset on the stm32L053C8
    [watchdog_sleep.cfg]
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2017-05-30 Start of STM32 board
    [stm32l053c.kicad_pcb, stm32l053c.sch]
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2017-05-31 3v3 LDO voltage regulator
    [stm32l053c.sch]
2017-05-31 Basic pinout
    [stm32l053c.sch]
2017-06-01 More connections
    [stm32l053c.sch]
2017-06-01 ADC connections
    [stm32l053c.sch]
2017-06-01 ADC footprint
    [stm32l053c.sch]
2017-06-02 Start of layout
    [stm32l053c.kicad_pcb, stm32l053c.sch]
2017-06-02 Initial layout
    [stm32l053c.kicad_pcb, stm32l053c.sch]
2017-06-03 Solar charging
    [stm32l053c.sch]
2017-06-04 DIO1 from the RFM module
    [stm32l053c.sch]
2017-06-04 Solar power
    [stm32l053c.kicad_pcb, stm32l053c.sch]
2017-06-04 UFL SMA antenna connector
    [stm32l053c.kicad_pcb, stm32l053c.sch]
2017-06-05 Compact layout + voltage dividers
    [stm32l053c.kicad_pcb, stm32l053c.sch]
2017-06-05 Battery box layout
    [stm32l053c.kicad_pcb, stm32l053c.sch]
2017-06-06 Solder mask clearance
    [stm32l053c.kicad_pcb]
2017-06-06 Start of traces
    [stm32l053c.kicad_pcb]
2017-06-06 Bigger board
    [stm32l053c.kicad_pcb, stm32l053c.sch]
2017-06-07 Fully routed
    [stm32l053c.kicad_pcb]
2017-06-07 Layout tweaks
    [stm32l053c.kicad_pcb]
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2017-06-08 Extra analog inputs
    [stm32l053c.kicad_pcb, stm32l053c.sch]
2017-06-08 Diode SOD-323
    [stm32l053c.kicad_pcb, stm32l053c.sch]
2017-06-08 Blink the LED with sleep
    [lora_sensor.cfg]
2017-06-09 Corrected analog pin connections
    [stm32l053c.kicad_pcb, stm32l053c.sch]
2017-06-09 Moved LED to default PA5
    [stm32l053c.kicad_pcb, stm32l053c.sch]
2017-06-09 Connect PA2
    [stm32l053c.kicad_pcb, stm32l053c.sch]
2017-06-09 More ground pins
    [stm32l053c.kicad_pcb, stm32l053c.sch]
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2017-06-14 Arduino example of setting & reading registers on the RFM95
2017-06-17 Connect all the pins of the RFM95 module
    [stm32l053c.kicad_pcb, stm32l053c.sch]
2017-06-17 Extra battery pins
    [stm32l053c.kicad_pcb, stm32l053c.sch]
2017-06-18 Serial RX
    [stm32l053c.kicad_pcb, stm32l053c.sch]
2017-06-18 An extra capacitor
    [stm32l053c.kicad_pcb, stm32l053c.sch]
2017-06-20 Pullup on ADC RDY pin
    [stm32l053c.kicad_pcb, stm32l053c.sch]
2017-06-20 Moved a couple of resistors
    [stm32l053c.kicad_pcb]
2017-06-21 DIO0_Pin is configured to interrupt on tx PacketSent
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2017-06-25 Pull up resistor for the DS18B20 one wire temperature sensor
    [stm32l053c.kicad_pcb, stm32l053c.sch]
2017-06-25 Extra 3v3 pins
    [stm32l053c.kicad_pcb, stm32l053c.sch]
2017-06-27 Shunt footprint change
    [stm32l053c.kicad_pcb]
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2017-06-28 Tidying ground pads
    [stm32l053c.kicad_pcb]
2017-07-31 Shift the I2C address to the most signifcant bits
2017-08-03 Measure battery voltage with the external ADC
    [stm32l053c.sch]
2017-08-03 I2C header
    [stm32l053c.sch]
2017-08-03 I2C power
    [stm32l053c.sch]
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2017-08-05 I2C layout
    [stm32l053c.kicad_pcb, stm32l053c.sch]
2017-08-07 Tweak traces
    [stm32l053c.kicad_pcb]
2017-08-07 Mk3.1 gerbers
    [stm32l053c-B.Cu.gbl, stm32l053c-B.Mask.gbs, stm32l053c-B.SilkS.gbo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]
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2017-08-24 Solder mask on the voltage regulator
    [stm32l053c.kicad_pcb]
2017-08-24 Larger D2 footprint
    [stm32l053c.kicad_pcb, stm32l053c.sch]
2017-08-24 Mk 3.2
    [stm32l053c.kicad_pcb]
2017-08-27 Set RFM95 reset high
    [main.c]
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2017-08-30 Do not use the reset pin (mcu hangs)
2017-08-31 Allow for the module power on reset time
    [rfm95.c]
2017-08-31 Pulse the reset line line then float
    [rfm95.c]
2017-08-31 Not using the pin interrupt for now as cases problems
    [main.c]
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2017-09-04 Take one high res lux reading then power down the lux module
2017-09-10 Longer sample time & take some junk readings
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2017-09-20 Show the mA charge on the led panel
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

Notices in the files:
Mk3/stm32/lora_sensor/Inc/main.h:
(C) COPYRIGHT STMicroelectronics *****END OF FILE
